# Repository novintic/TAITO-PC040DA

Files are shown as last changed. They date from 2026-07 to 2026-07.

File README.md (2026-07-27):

A reproduction of the TAITO PC040DA digital-to-analog converter hybrids used in the videocircuitry on some TAITO boards like Bubble Bobble.

the simpler version uses a weighted resistor- network with more or less common values. It works well on Bubble Bobble.

There's also a version with an OPamp to amplify the output. This version has not really been tested as the one without seems to just work well..

Please understand that we are not able to offer any support. Use at your own risk. Thank you.

NOVINTIC 2026

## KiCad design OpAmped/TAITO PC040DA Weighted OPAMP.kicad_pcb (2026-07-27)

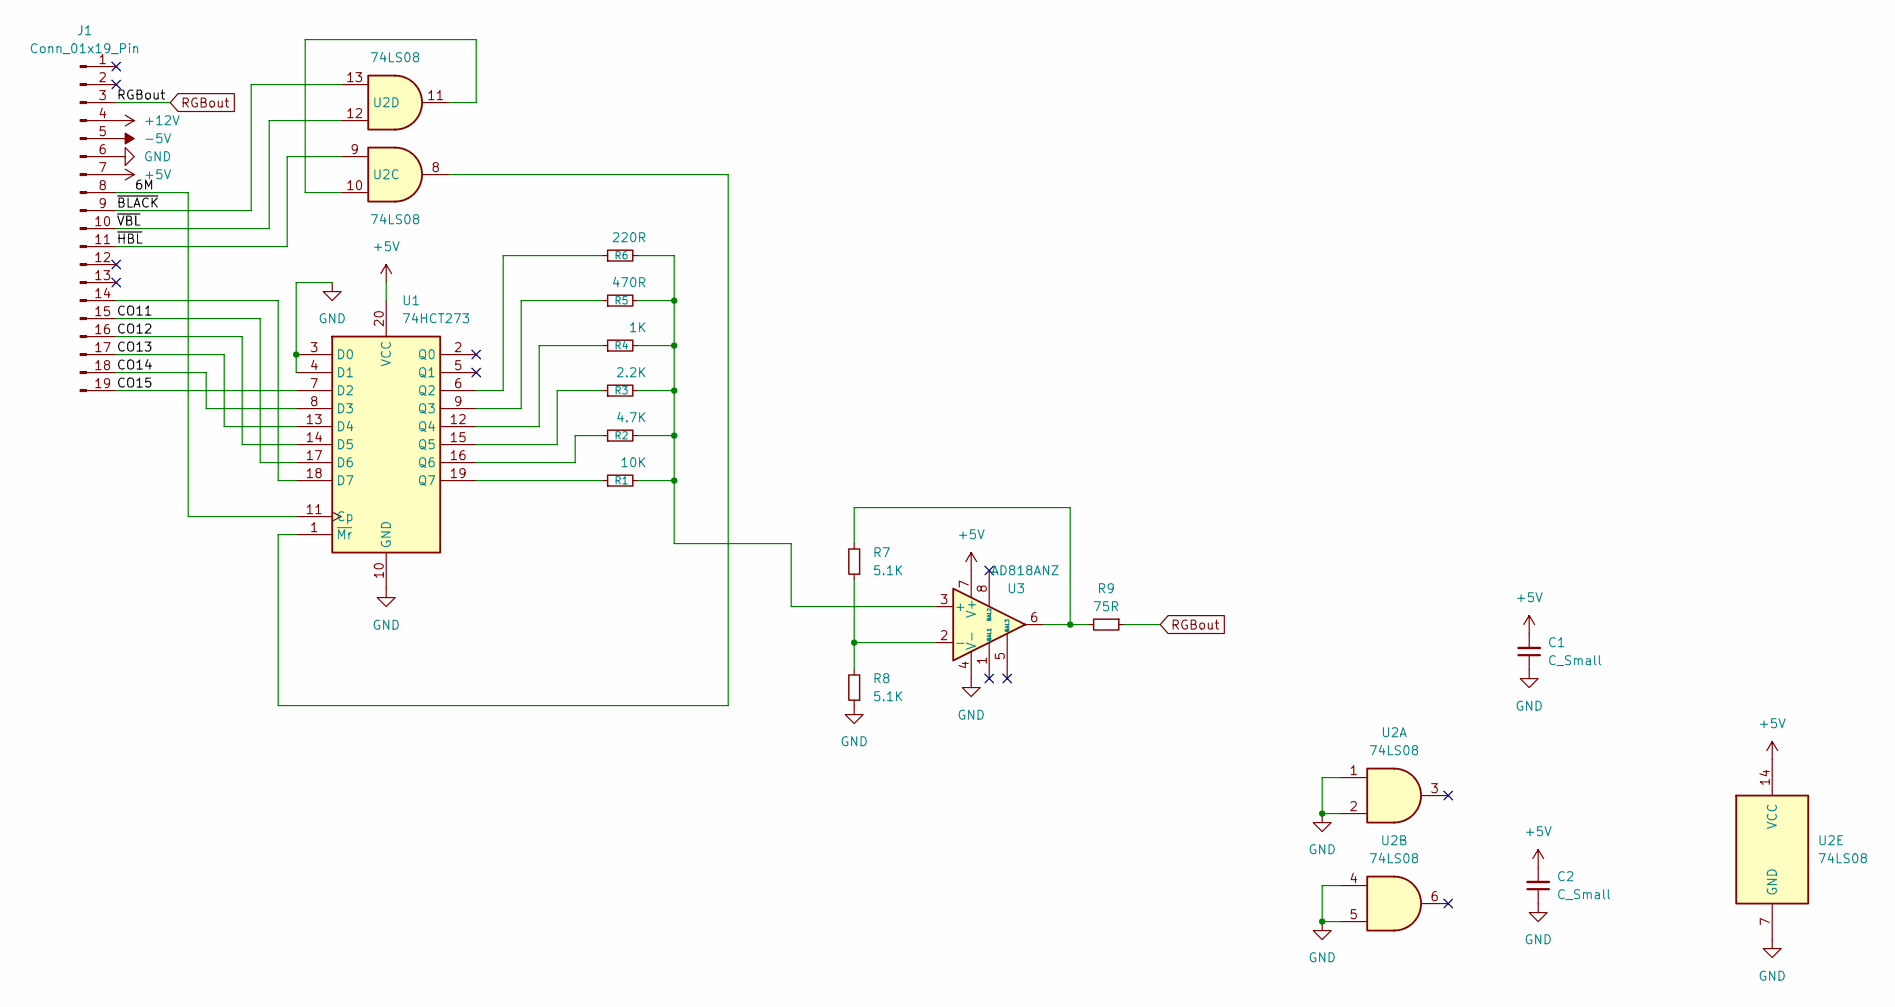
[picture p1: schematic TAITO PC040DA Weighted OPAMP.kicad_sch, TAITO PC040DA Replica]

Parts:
C1, C2: C_Small; C_0805_2012Metric_Pad1.18x1.45mm_HandSolder
J1: Conn_01x19_Pin; PinHeader_1x19_P2.54mm_Vertical
R1: 10K; R_0805_2012Metric_Pad1.20x1.40mm_HandSolder
R2: 4.7K; R_0805_2012Metric_Pad1.20x1.40mm_HandSolder
R3: 2.2K; R_0805_2012Metric_Pad1.20x1.40mm_HandSolder
R4: 1K; R_0805_2012Metric_Pad1.20x1.40mm_HandSolder
R5: 470R; R_0805_2012Metric_Pad1.20x1.40mm_HandSolder
R6: 220R; R_0805_2012Metric_Pad1.20x1.40mm_HandSolder
R7, R8: 5.1K; R_0805_2012Metric_Pad1.20x1.40mm_HandSolder; LCSC C26023
R9: 75R; R_0805_2012Metric_Pad1.20x1.40mm_HandSolder; LCSC C431854
U1: 74HCT273; TSSOP-20_4.4x6.5mm_P0.65mm
U2: 74LS08; SOIC-14_3.9x8.7mm_P1.27mm
U3: AD818ANZ; SOIC-8_3.9x4.9mm_P1.27mm; LCSC C128749

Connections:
+5V: C1.2, C2.2, J1.7, U1.20 (VCC), U2.14 (VCC), U3.7 (V+)
+12V: J1.4
-5V: J1.5
/6M: J1.8, U1.11 (Cp)
/CO11: J1.15, U1.17 (D6)
/CO12: J1.16, U1.14 (D5)
/CO13: J1.17, U1.13 (D4)
/CO14: J1.18, U1.8 (D3)
/CO15: J1.19, U1.7 (D2)
/~BLACK: J1.9, U2.13
/~HBL: J1.11, U2.9
/~VBL: J1.10, U2.12
GND: C1.1, C2.1, J1.6, R8.1, U1.3 (D0), U1.4 (D1), U1.10 (GND), U2.1, U2.2, U2.4, U2.5, U2.7 (GND), U3.4 (V-)
unnamed: J1.14, U1.18 (D7)
unnamed: R7.2, R9.2, U3.6
unnamed: R6.1, U1.6 (Q2)
unnamed: R5.1, U1.9 (Q3)
unnamed: R4.1, U1.12 (Q4)
unnamed: R3.1, U1.15 (Q5)
unnamed: R2.1, U1.16 (Q6)
unnamed: R1.1, U1.19 (Q7)
unnamed: U1.1 (~Mr), U2.8
unnamed: U2.10, U2.11
unnamed: R1.2, R2.2, R3.2, R4.2, R5.2, R6.2, U3.3 (+)
unnamed: R7.1, R8.2, U3.2 (-)
RGBout: J1.3, R9.1; also elsewhere on the board

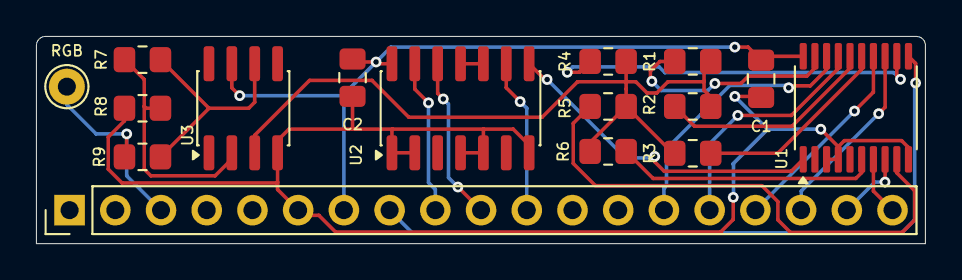
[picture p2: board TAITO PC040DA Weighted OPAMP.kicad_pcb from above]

Board: 2 copper layers, 49.4 x 11.5 mm, 16 parts (0 on the bottom side), 24 nets.

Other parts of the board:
RGB: TestPoint_THTPad_D2.0mm_Drill1.0mm

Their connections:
RGBout: RGB.1; also elsewhere on the board
